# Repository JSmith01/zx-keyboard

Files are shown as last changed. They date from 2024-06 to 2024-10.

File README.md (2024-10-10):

# Another (ZX/PC) keyboard case with Cherry MX switches

## Layout

4 were designed:
* `delta` reproduces classic ZX Spectrum+ / Delta-S clone keyboard

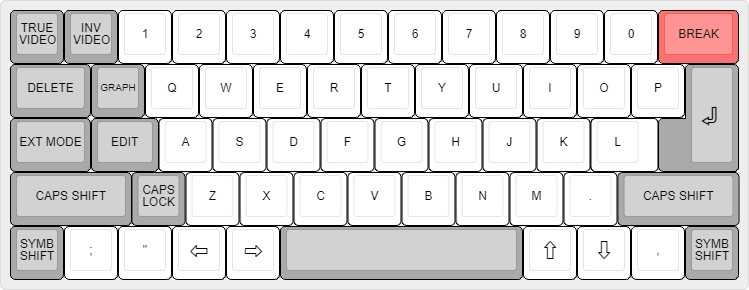
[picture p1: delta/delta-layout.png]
Delta-S layout
  

* `next-like` follows ZX Spectrum Next quite closely, but uses standard third letter row shift of 0.5u instead of Next's non-standard 0.75u. Some other keys were swapped to keep it closer to the Spectrum+ layout.
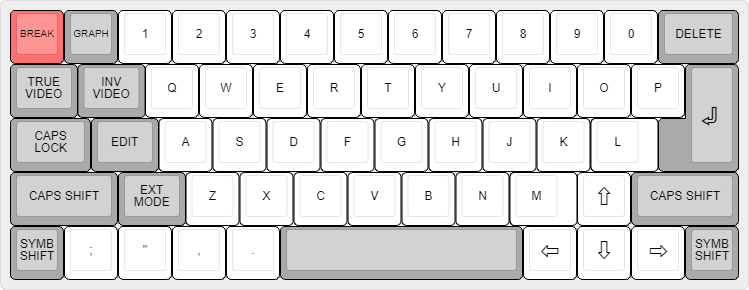
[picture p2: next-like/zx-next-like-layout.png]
ZX Next-like layout
  

* `13u` uses slightly condensed layout, requires only one stabilizer and only one stepped 1.25u key. Additionally it fits my 3d printer plate (256 mm square).

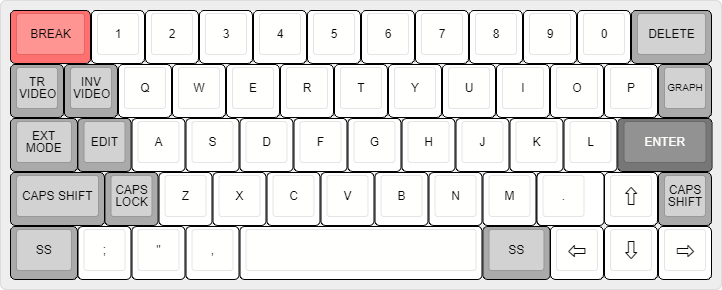
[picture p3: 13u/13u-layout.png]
13u condensed layout
  

* `13u-pc` PC-like keyboard to fit into 13u limit, requires 2 stabilizers, keycaps can be either printed or bought (however, some keys are barely of standard sizes).

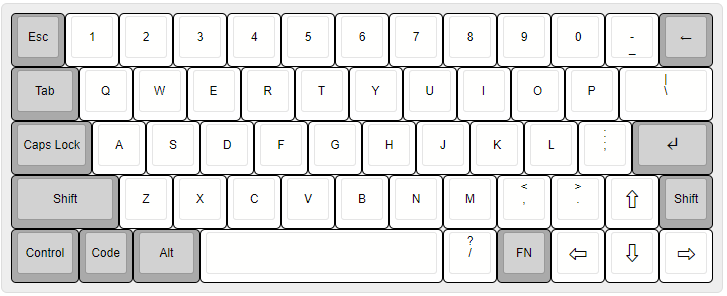
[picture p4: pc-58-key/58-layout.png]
13u-pc condensed layout
  

## Keycap models (Karon/Kopir-like)

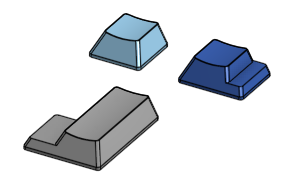
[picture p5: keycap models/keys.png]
ZX keyboard keys


`.step` files are in `keycap models` directory, and the source can be found in the onshape CAD:

https://cad.onshape.com/documents/8eec099704dd56ee90a99779/w/f094e603417fd53c8f53642f/e/6200ad26f37156b8d2f7b3c0 (needs free account)

### Model params
* `#h_units` - 1u key only (horizontal units, supports 1-3u, 4.5u, 6.25u)
inside 1u key group - #stab_dist - formula to calculate distance between main key switch mount and stab mounts. Change it to support spacebars different from 4.5u/6.25u.
* `#side_angle` (25 deg) 
* `#front_angle` (35 deg)
* `#rear_angle` (5 deg)
* `#key_bend` (0.6mm) - amount of key surface bending, mm. 0.01mm is the minimum, also 4.5u automatically uses 0.01mm (flat surface for 3d printing)

All keycap parameters are set after Delta-S keyboard (Kopir / Karon factories), except the slightly bigger base key size. Here it is 18mm, common size for Cherry MX-based key switches, and on the real ZX keyboard it was 17.8 - 0.27mm according to factory blueprints (found an archive with it on the zx-pk.ru forum) - see `keycap blueprints` directory (all labels there are in Russian).

MX key spacebar stabilizer positions come from https://deskthority.net/wiki/Space_bar_dimensions

Other keycap dimensions are from https://blog.maxkeyboard.com/dwkb/keycap-profile-size-information/

Layout design service used: http://www.keyboard-layout-editor.com/
Plate generation service used: http://builder.swillkb.com/

## 13u wide keyboard case for a wedge case computer (WIP)

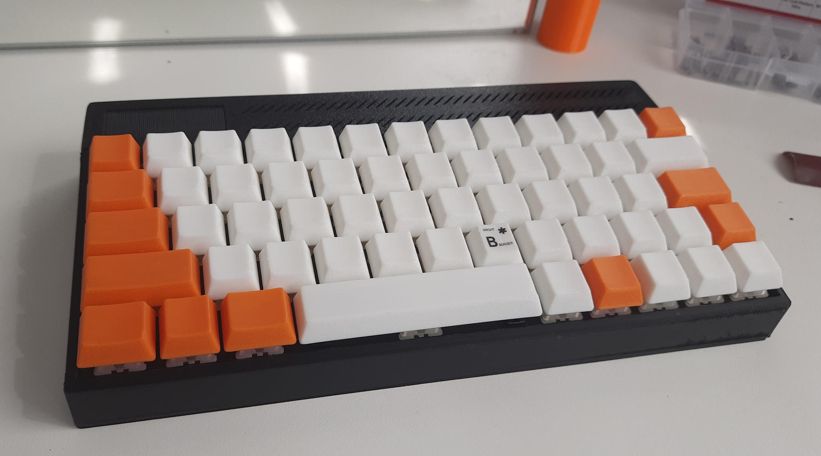
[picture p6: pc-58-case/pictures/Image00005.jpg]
RPi Zero 2 W wedge case computer


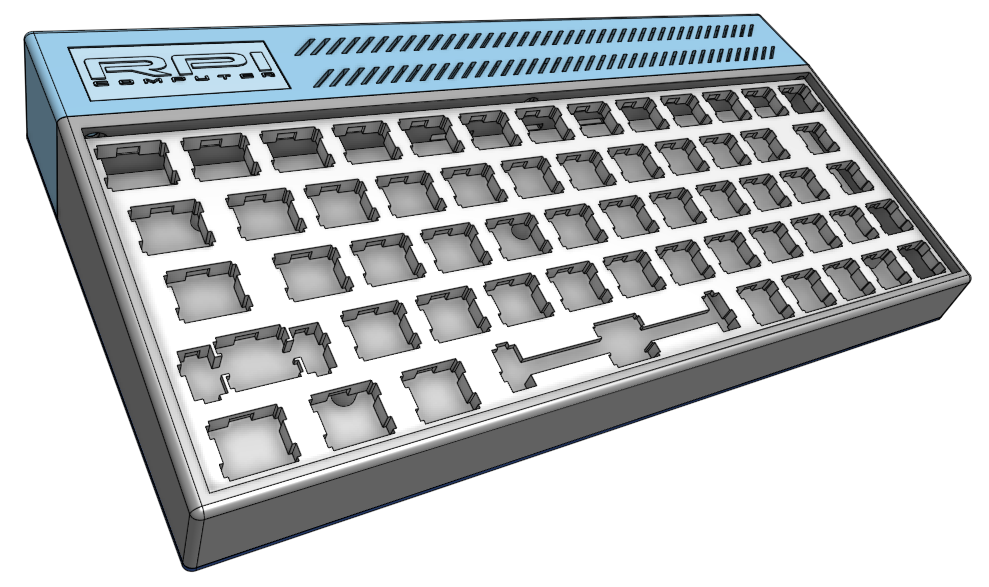
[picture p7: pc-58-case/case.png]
RPi Zero 2 W wedge case computer


Files for case parts are in `pc-58-case` directory. The main design constraint was, again, to fit each piece entirely into my 3d printer volume (cube of 256mm).

For my implementation I chose RPi 2 Zero W as a main board, mainly because of its low price and the fact I already had one. The design is parametric and it can be changed to adopt almost any board. The back cover of the case is a separate piece, so in case of re-printing it would require changing of the bottom piece and the back. The plate and the front keyboard case will remain unchanged. The case design is WIP still, however, I was able to print the plate, keycaps, and assemble it.

CAD link: https://cad.onshape.com/documents/80a6f71aa4ea5afbe3c2f400/w/0c9d95387bdbef7828758cf6/e/f104cb4e70454155592a95cd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

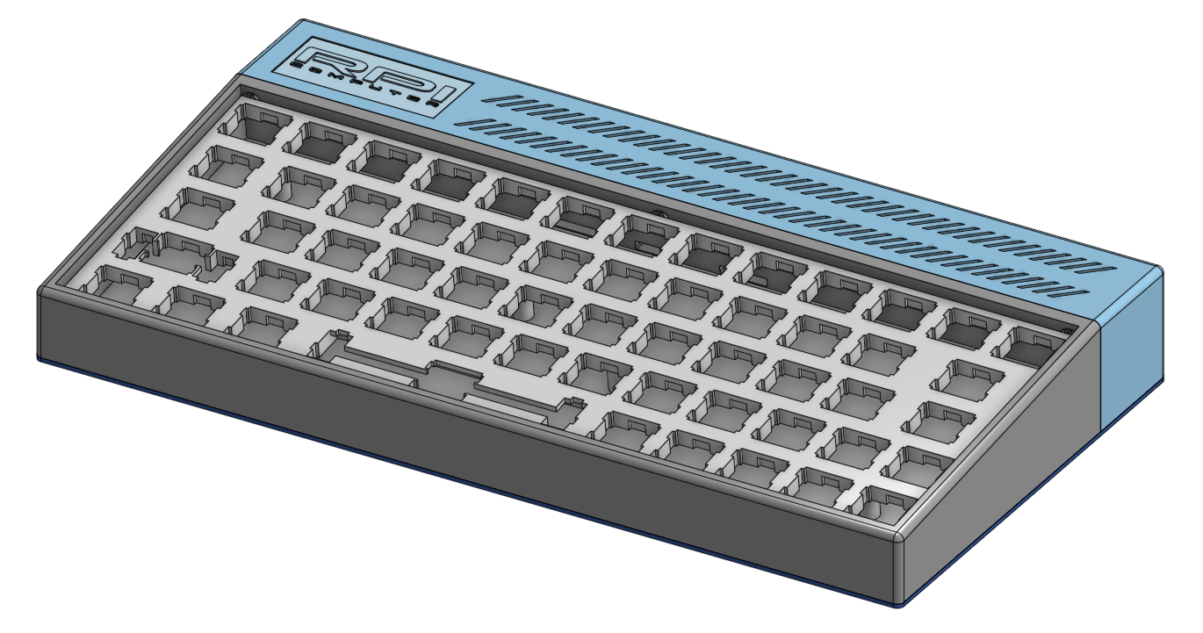
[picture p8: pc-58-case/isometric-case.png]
RPi Zero 2 W wedge case computer


### 13u wide keyboard layout (PC like)

The directory `pc-58-key` has all the files for the layout, keycaps used, plate `.dxf` file. For the design, the only concerns were to fit into 13u limit, and have dedicated cursor keys (I hope it would help with retro gaming).

RPi Zero 2 W wedge case computer

It uses the same keycap models as ZX keys, but with other parameters:
* `#side_angle` (20 deg) 
* `#front_angle` (30 deg)
* `#rear_angle` (1 deg)

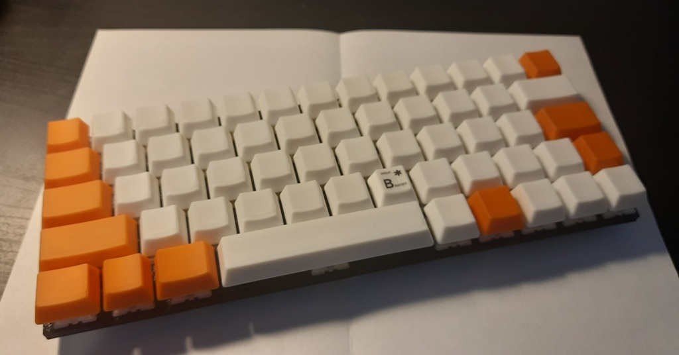
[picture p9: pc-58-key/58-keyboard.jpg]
58 keyboard 13u wide


The keyboard needs 58 key switches (I used yellow gaterons), and 2 stabilizers - 2u and 4.5u (uncommon, but see below about using common 6.25u).

## Re-bending key stabilizers from 6.25u / 6.5u / 7u to 4.5u

Since I didn't find plate mounted stabilizers for 4.5u space, I had to bend the existing 6.25u stab to the needed dimension. This is a small guiding tool that helps to re-bend stab rod to the size of 4.5u. It requires two M2 screw bolts, 6-10mm long each. The model can be found in `auxilliary` directory.

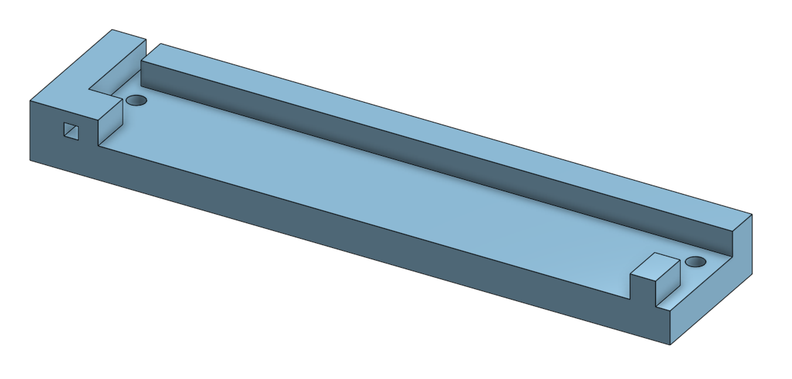
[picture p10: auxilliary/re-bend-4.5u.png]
re-bend tool to 4.5u


CAD link:
https://cad.onshape.com/documents/ae3792f91f504da8d6e72a6f/w/ced467ad9bcd54dddc1017f0/e/babc9538a75bcf5462f88daf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

# Wiring

I wired keyboard using 1N4148 diodes, that I solder their pins to each other making rows, similar to the process shown in this video: [Hand-wiring a custom layout keyboard](https://youtu.be/3uSKgCuK3tc?si=MMpzzscPRhe9YTKL&t=43). The only difference I bend diodes upfront, so I've made a tool for that. Files can be found in the `auxilliary` directory.

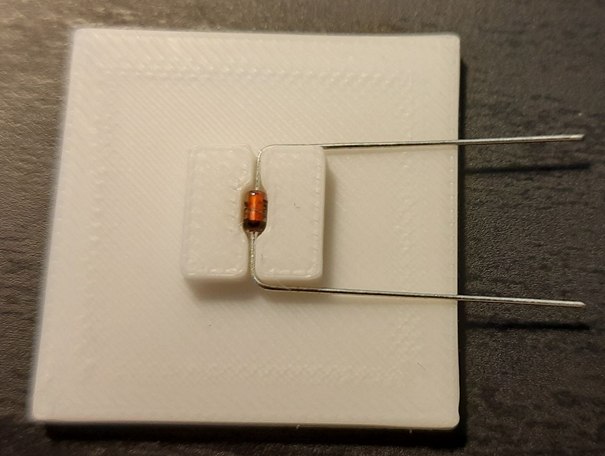
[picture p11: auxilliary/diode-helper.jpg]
diode helper


Result looks like this (I use 8mm wide capton tape for isolation):

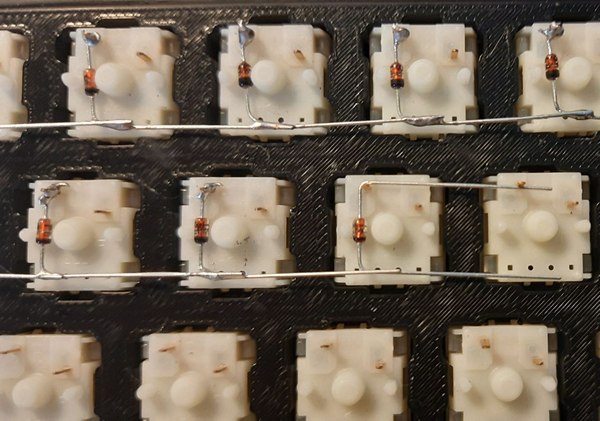
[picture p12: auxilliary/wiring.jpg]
wiring in process


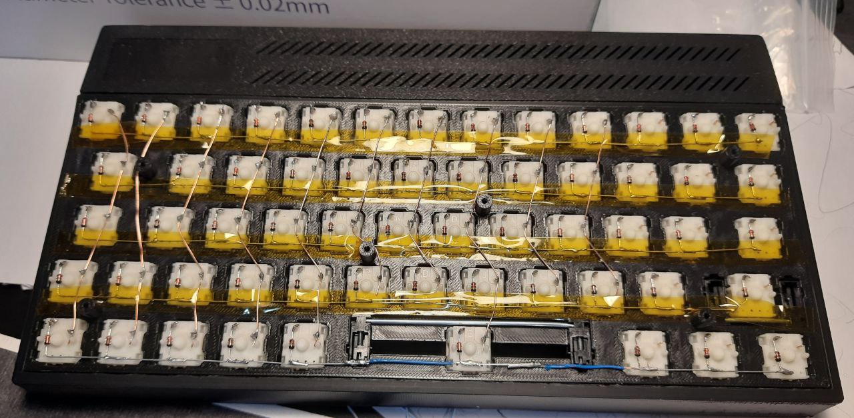
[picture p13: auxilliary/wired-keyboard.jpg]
wired keyboard


## Tool for converting KLE .json to .svg

To prepare keycap labels it will be useful to create SVGs from appropriate layout files. So I've created `kle2svg` tool to do so.
It's pretty limited for its support for KLE features, but works for my layouts.

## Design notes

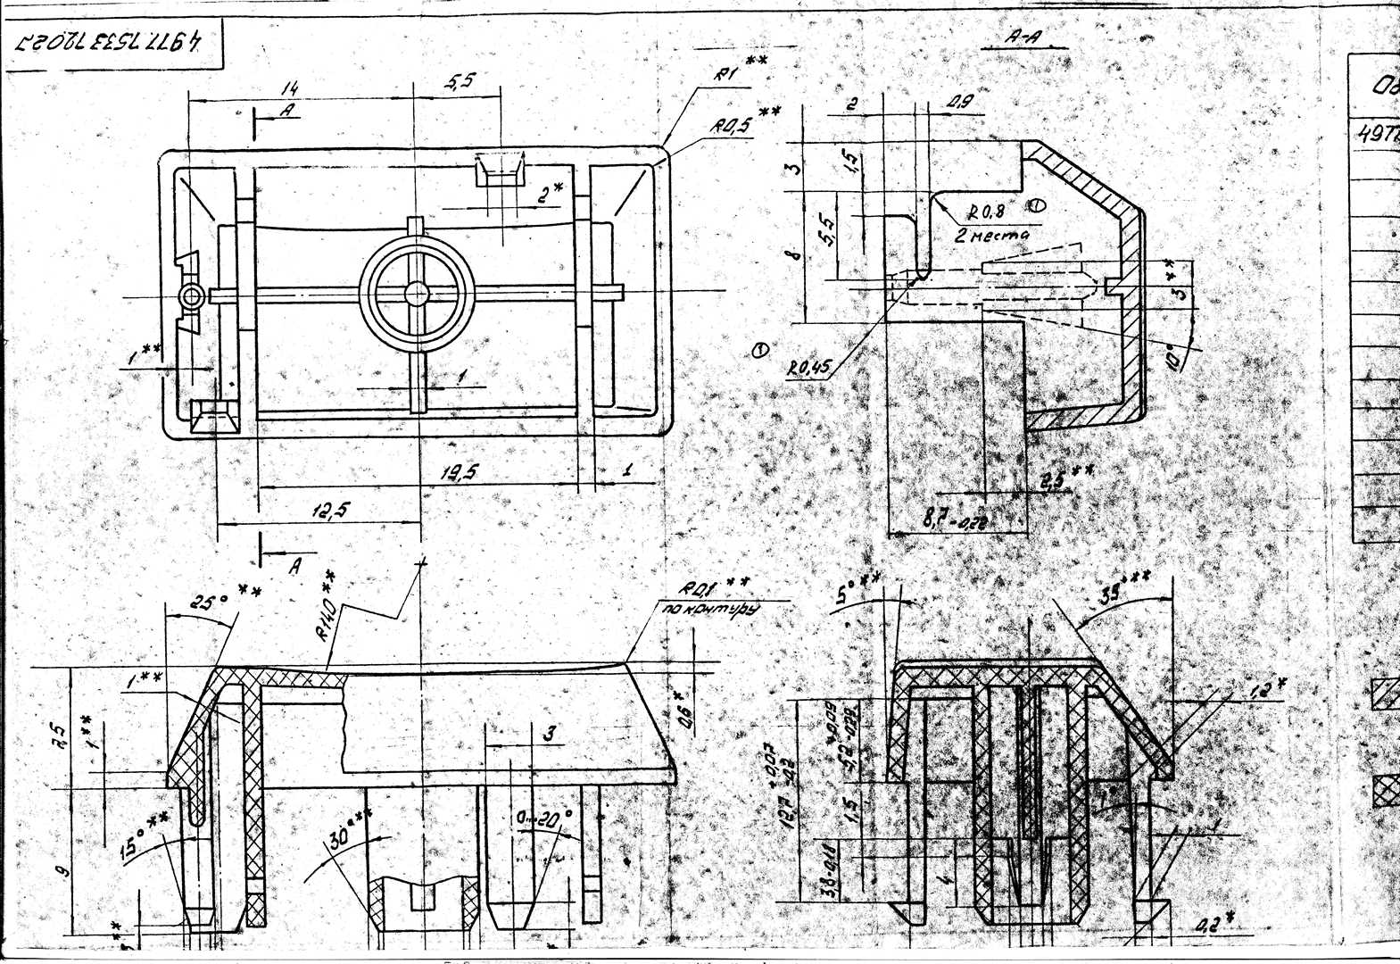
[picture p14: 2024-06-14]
keycap blueprints/key 6-1.jpg

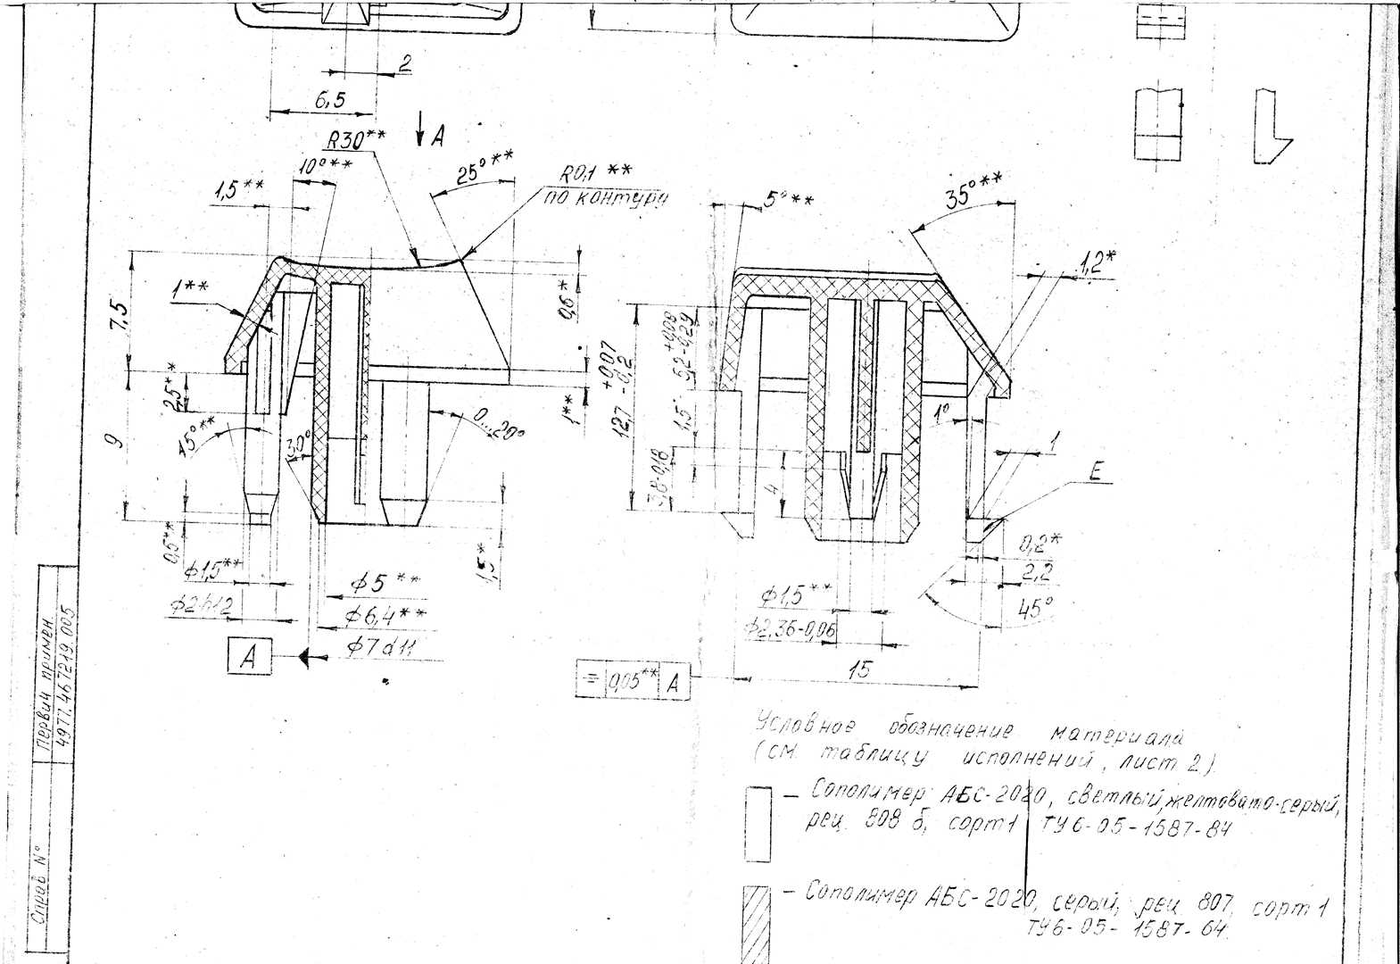
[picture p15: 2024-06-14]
keycap blueprints/key 1-2.jpg

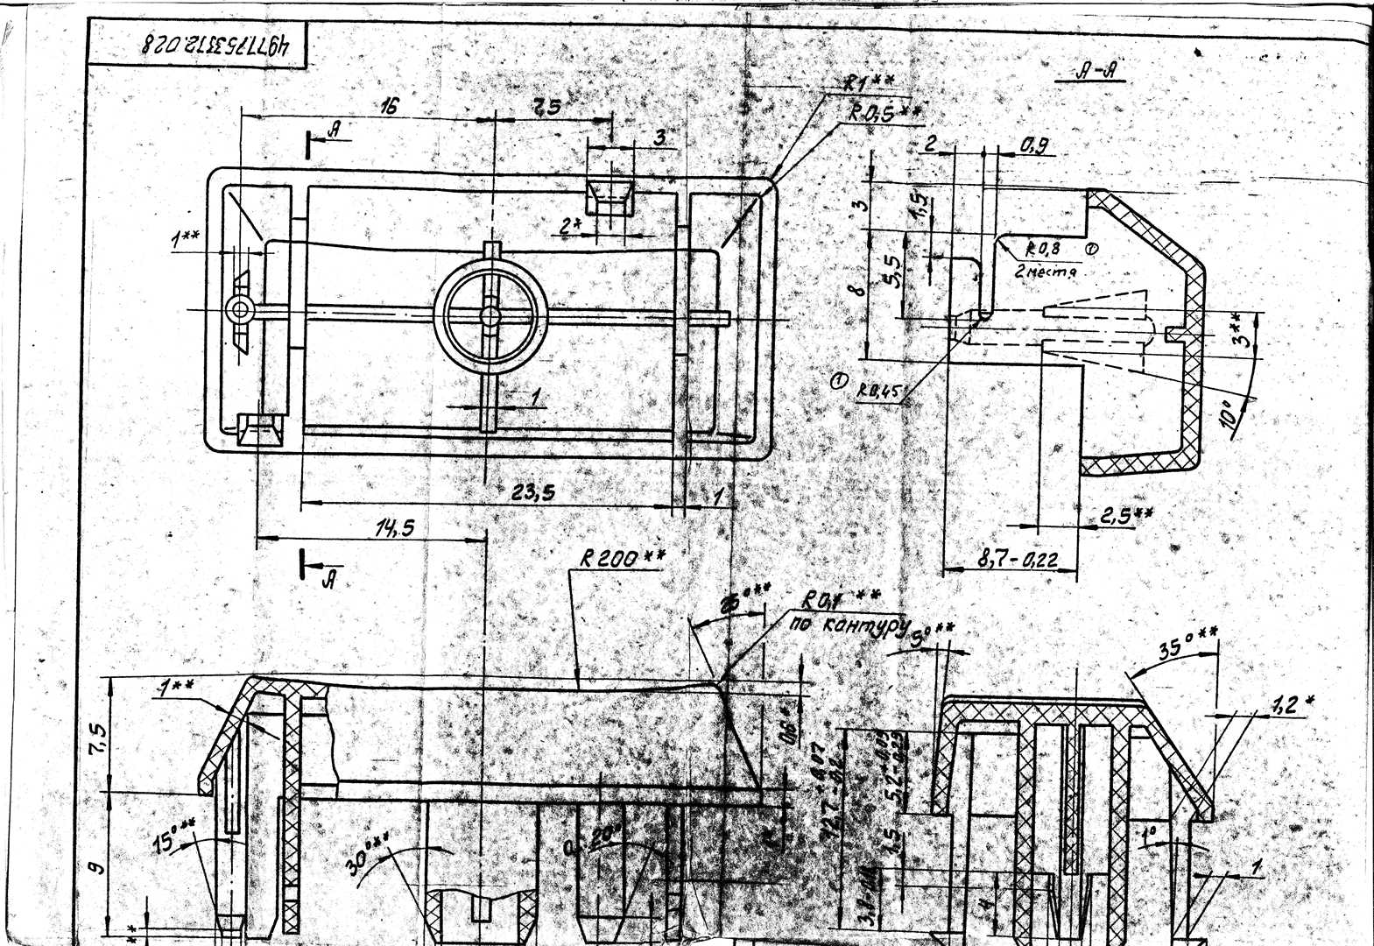
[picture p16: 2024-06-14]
keycap blueprints/key 5-1.jpg

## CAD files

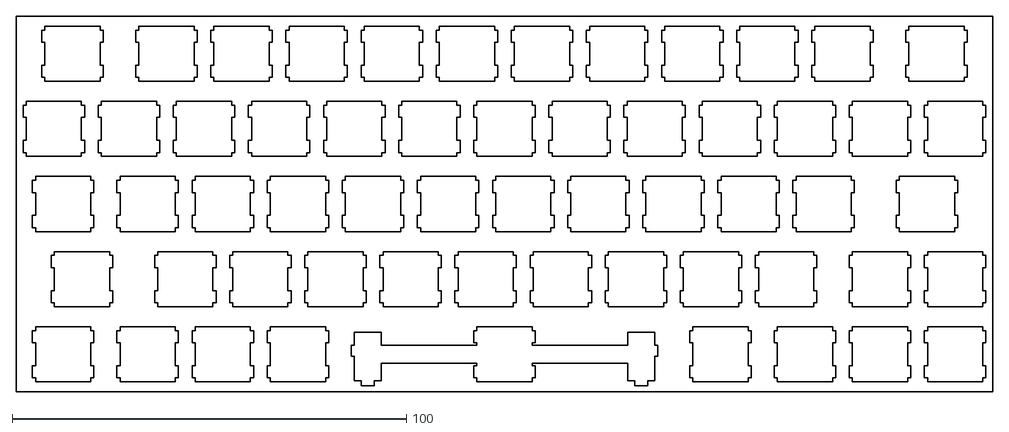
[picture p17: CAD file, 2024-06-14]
13u/13u-plate.dxf
247.6 x 95.2

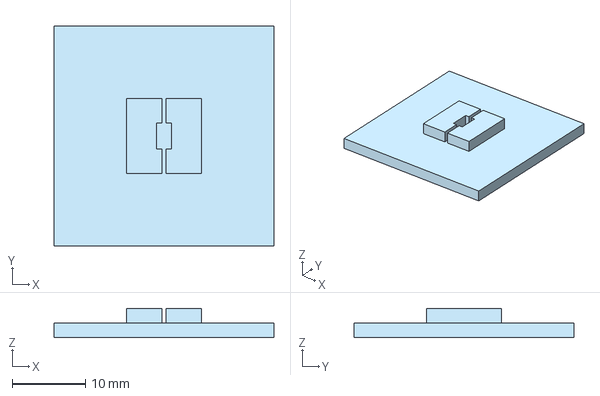
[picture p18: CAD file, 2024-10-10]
auxilliary/diode-helper.step
30.0 x 30.0 x 4.00 mm

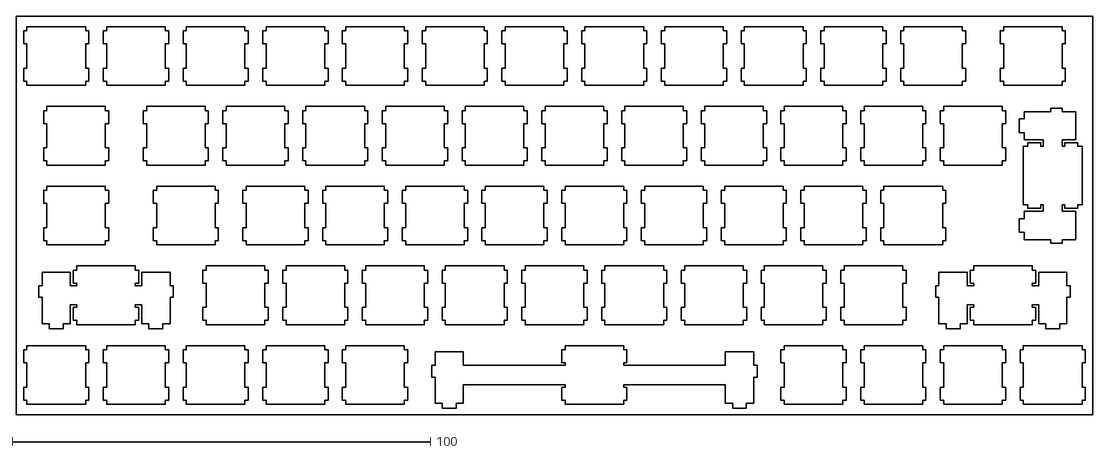
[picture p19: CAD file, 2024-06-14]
delta/delta-plate.dxf
257.2 x 95.2

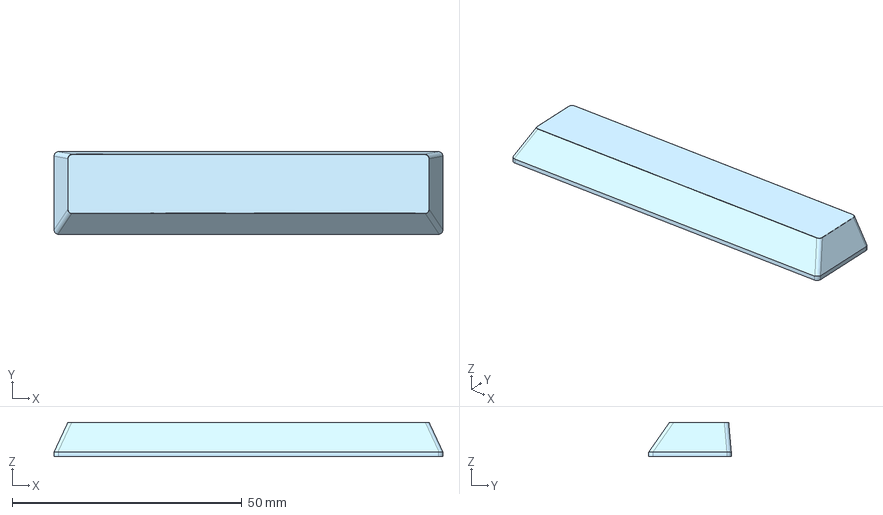
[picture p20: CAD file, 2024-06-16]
keycap models/4_5u key.step
84.7 x 18.0 x 7.50 mm

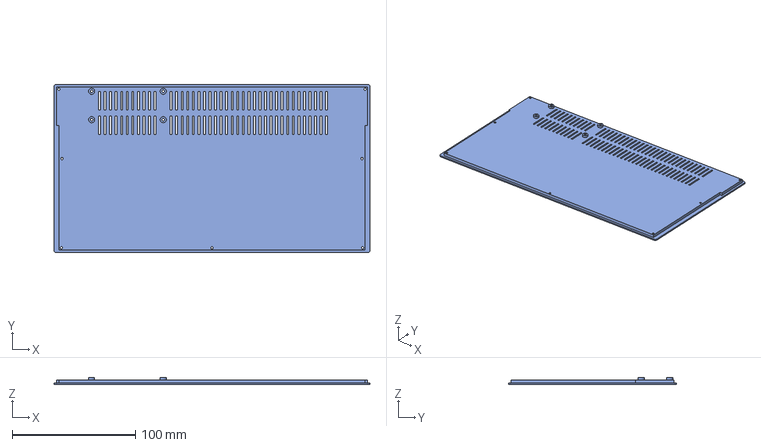
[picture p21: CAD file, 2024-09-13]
pc-58-case/bottom.step
256.0 x 136.5 x 6.00 mm

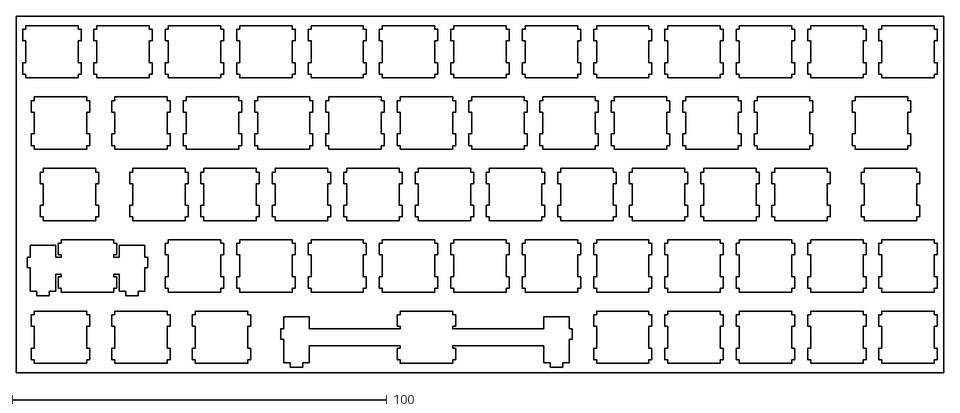
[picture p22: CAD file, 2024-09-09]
pc-58-key/13u-pc.dxf
247.6 x 95.2

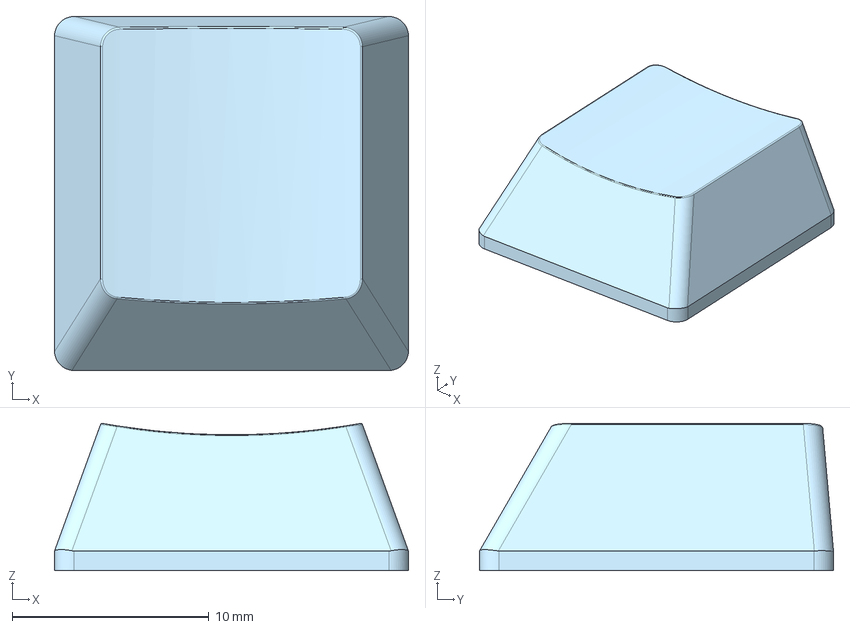
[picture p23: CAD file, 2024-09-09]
pc-58-key/keycap-models/pc 1u key.step
18.0 x 18.0 x 7.49 mm

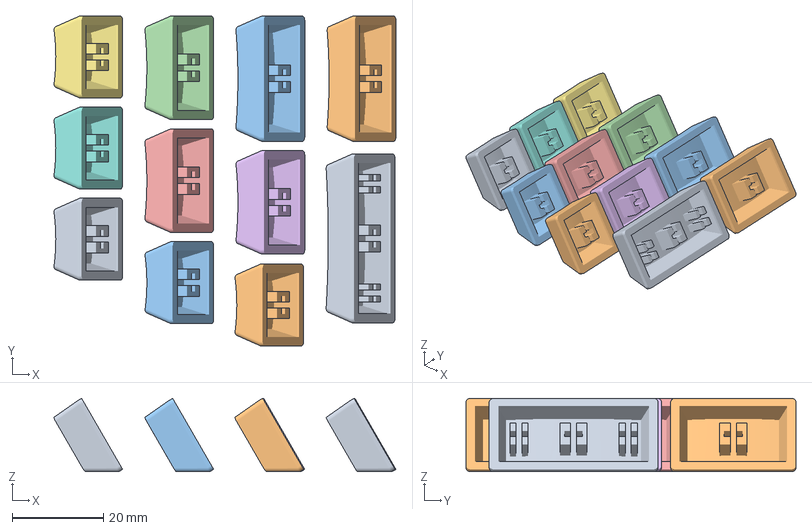
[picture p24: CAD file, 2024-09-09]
pc-58-key/keycaps/pc - color keys.3mf
75.1 x 72.4 x 16.1 mm
pc 2u key.step
pc 1.5u key.step x 2
pc 1.25u key.step x 3
pc 1u key.step x 5

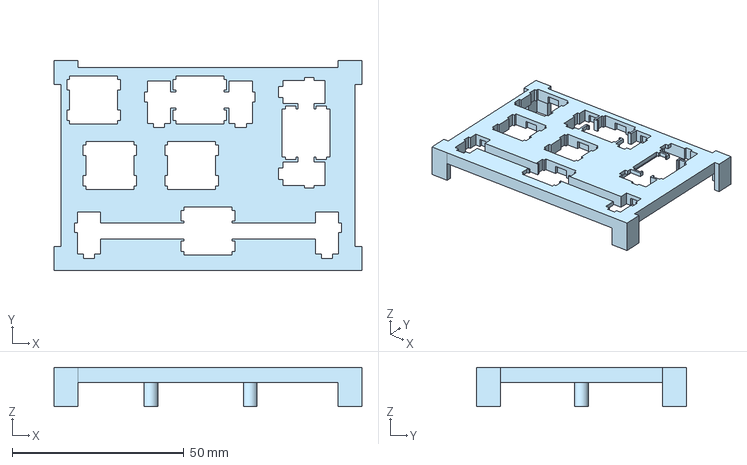
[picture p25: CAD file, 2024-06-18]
test/keys-test-plate.step
89.7 x 61.2 x 11.5 mm

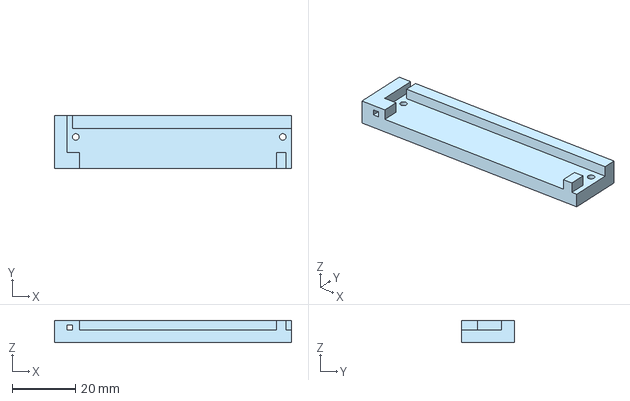
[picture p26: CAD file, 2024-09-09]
auxilliary/re-bend tool to 4.5u.step
75.1 x 16.7 x 7.00 mm

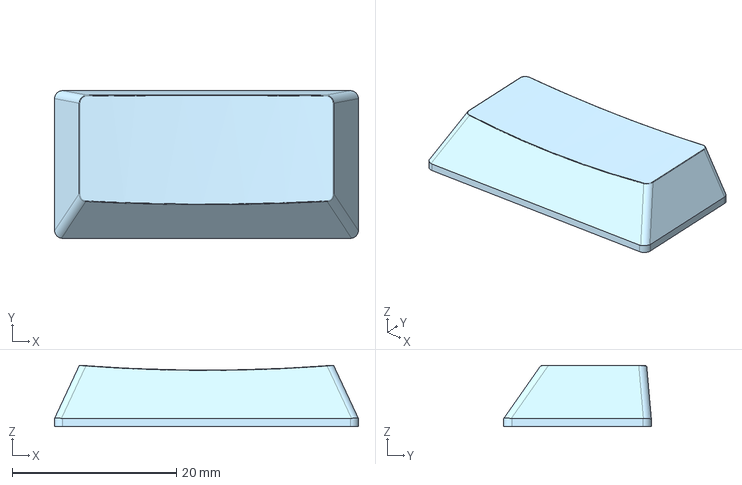
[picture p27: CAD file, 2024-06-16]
keycap models/2u key.step
37.0 x 18.0 x 7.49 mm

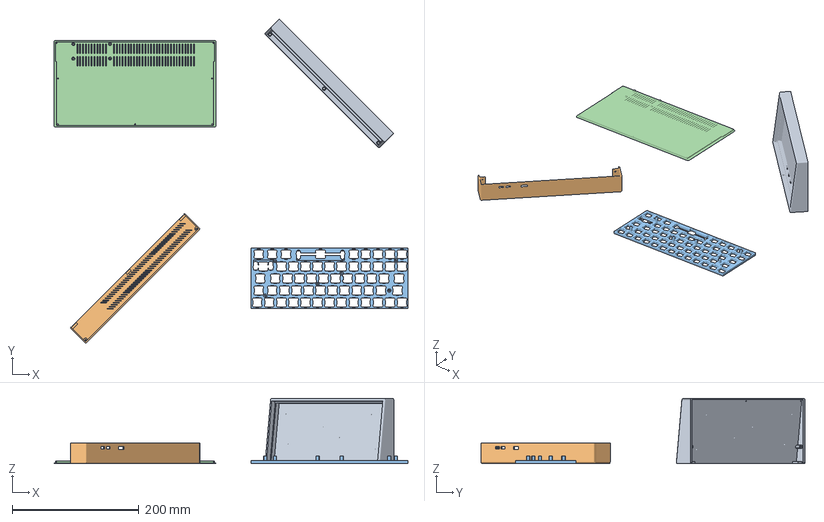
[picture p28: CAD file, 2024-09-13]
pc-58-case/case.3mf
559.0 x 511.6 x 102.7 mm
front.step
back.step
plate.step
bottom.step

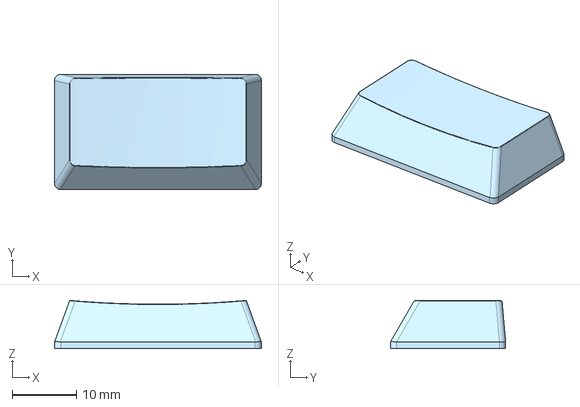
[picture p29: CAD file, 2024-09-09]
pc-58-key/keycap-models/pc 1.75u key.step
32.3 x 18.0 x 7.49 mm

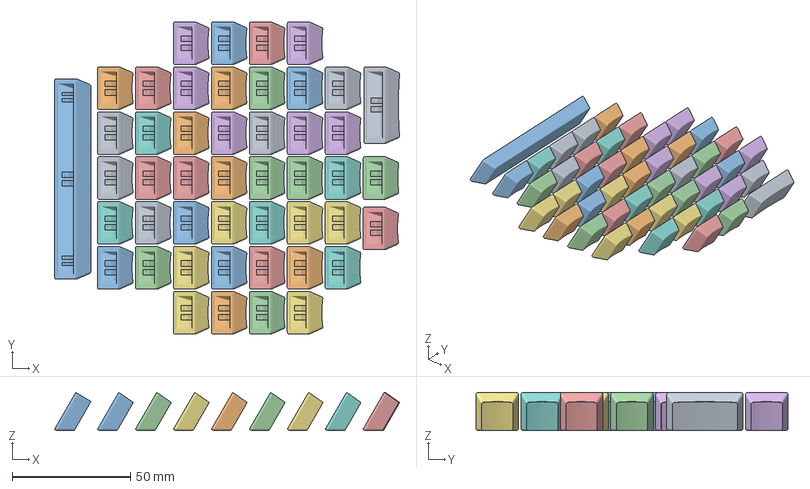
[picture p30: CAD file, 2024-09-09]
pc-58-key/keycaps/pc - keys white.3mf
146.0 x 132.0 x 16.1 mm
pc 1.75u key.step
pc 1u key.step x 45
pc 4.5u key.step

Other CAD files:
test/test-plate.dxf
keycap models/1_25u stepped key.step
pc-58-case/back.step
auxilliary/diode-helper.3mf
keycap models/1_25u key.step
keycap models/1_25u stepped.step
keycap models/1_5u key.step
keycap models/1_75u key.step
keycap models/1u key.step
keycap models/2_25u key.step
keycap models/2u Enter.step
keycap models/6_25u key.step
pc-58-case/front.step
pc-58-case/label.step
pc-58-case/plate.step
pc-58-key/keycap-models/pc 1.25u key.step
pc-58-key/keycap-models/pc 1.5u key.step
pc-58-key/keycap-models/pc 2u key.step
pc-58-key/keycap-models/pc 4.5u key.step
test/keys-test-plate.3mf

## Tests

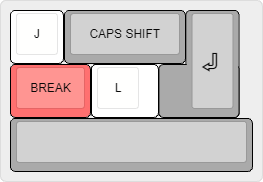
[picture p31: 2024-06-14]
test/keyboard-layout-test.png

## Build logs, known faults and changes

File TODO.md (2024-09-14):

# TODO

* make a tool for bending diodes
* fix loose 4.5u space stab fastenings (tighter clearance mb?)
* create key labels for layouts
* create 13.5u version of the case
* create plate models for other layouts
* make back compartment variants for RPI 4/5/Radxa 4X

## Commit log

2024-06-14 added 2u plain key
    [2u key.step]
2024-06-16 fixed stab and keyswitch mount
    [1_25u key.step, 1_25u stepped key.step, 1_5u key.step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]
2024-06-18 fixed test plate to be sturdy enough
    [keys-test-plate.3mf, keys-test-plate.step, zx-keys-test-plate.3mf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]
2024-06-18 added hotswap socket found in the onshape
    [hotswap mx solderable v7.3mf, hotswap mx solderable v7.step]
2024-09-09 a wedge case added
    [13u-pc.dxf, back.step, bottom.step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]
2024-09-13 printed case pictures added, updated case .3mf file
    [case.3mf]
2024-09-13 updated bottom part
    [bottom.step, case.3mf]
2024-09-14 added todo, removed unused hotswap keyswitch socket model
    [hotswap mx solderable v7.3mf, hotswap mx solderable v7.step]
2024-10-10 wiring (added directory)
